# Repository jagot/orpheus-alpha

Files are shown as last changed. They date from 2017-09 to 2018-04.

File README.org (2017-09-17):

#+TITLE: Ορφέας Άλφα preamplifier
#+AUTHOR: Stefanos Carlström
#+EMAIL: stefanos.carlstrom@gmail.com

A simple preamplifier based around OPA2134 as buffer stage and PGA2311
as volume controller. A PSU (design [[https://www.muffsy.com/build-the-muffsy-psu-v3.html][courtesy of Muffsy]]) is also
present on the board, which is to be powered with 6VAC. Input signal
should be around Red Book standard.

[[./orpheus-alpha.pdf][Schematic]]

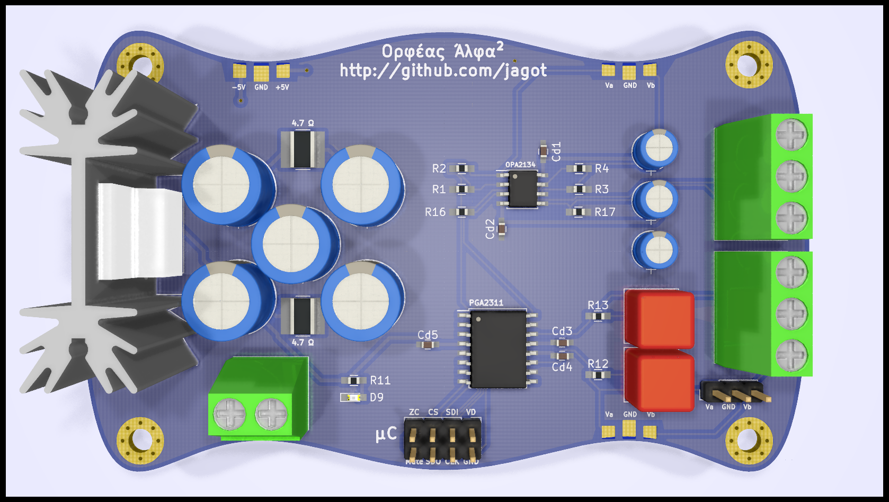
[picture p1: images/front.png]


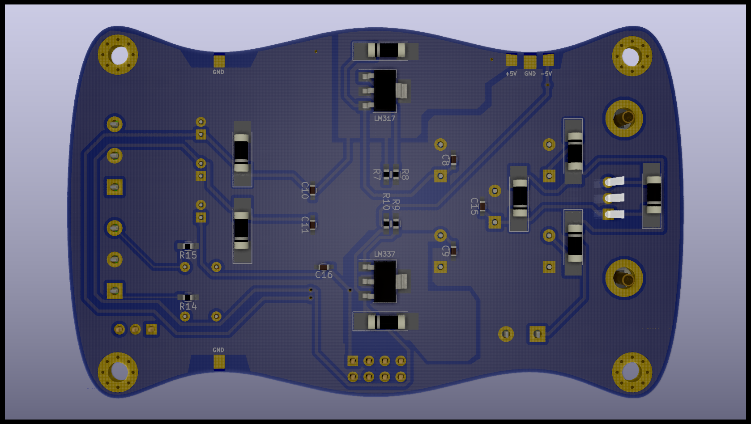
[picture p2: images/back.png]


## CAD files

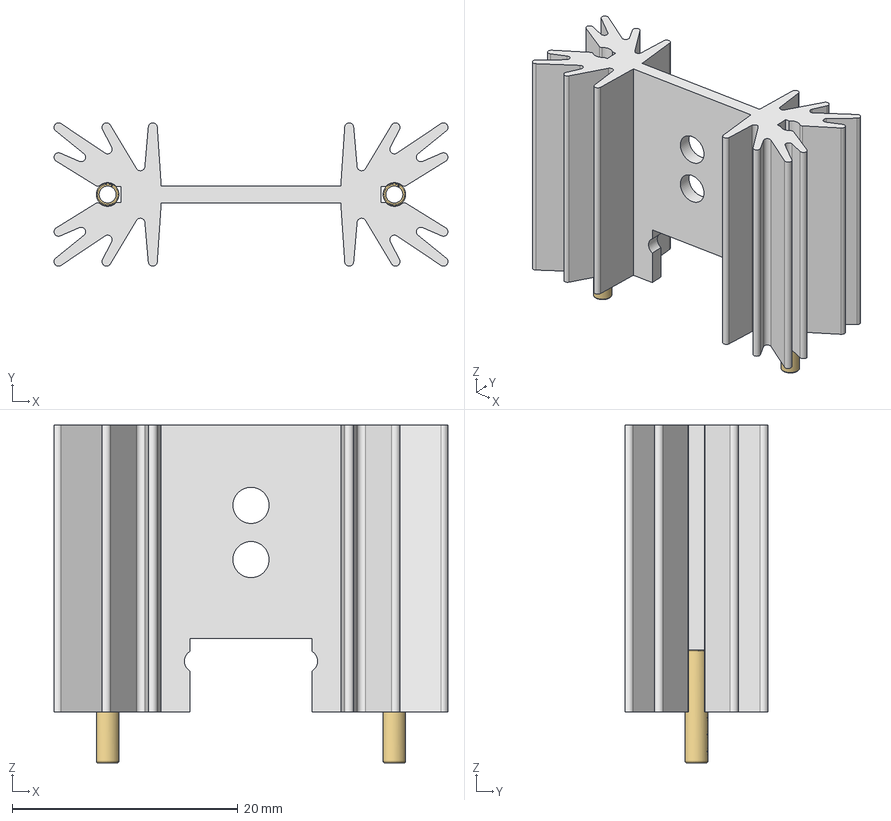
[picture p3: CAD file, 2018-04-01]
shapes3D/sk_104_25.4_sts.stp
34.9 x 12.7 x 29.9 mm
A9001B20100008S x 2

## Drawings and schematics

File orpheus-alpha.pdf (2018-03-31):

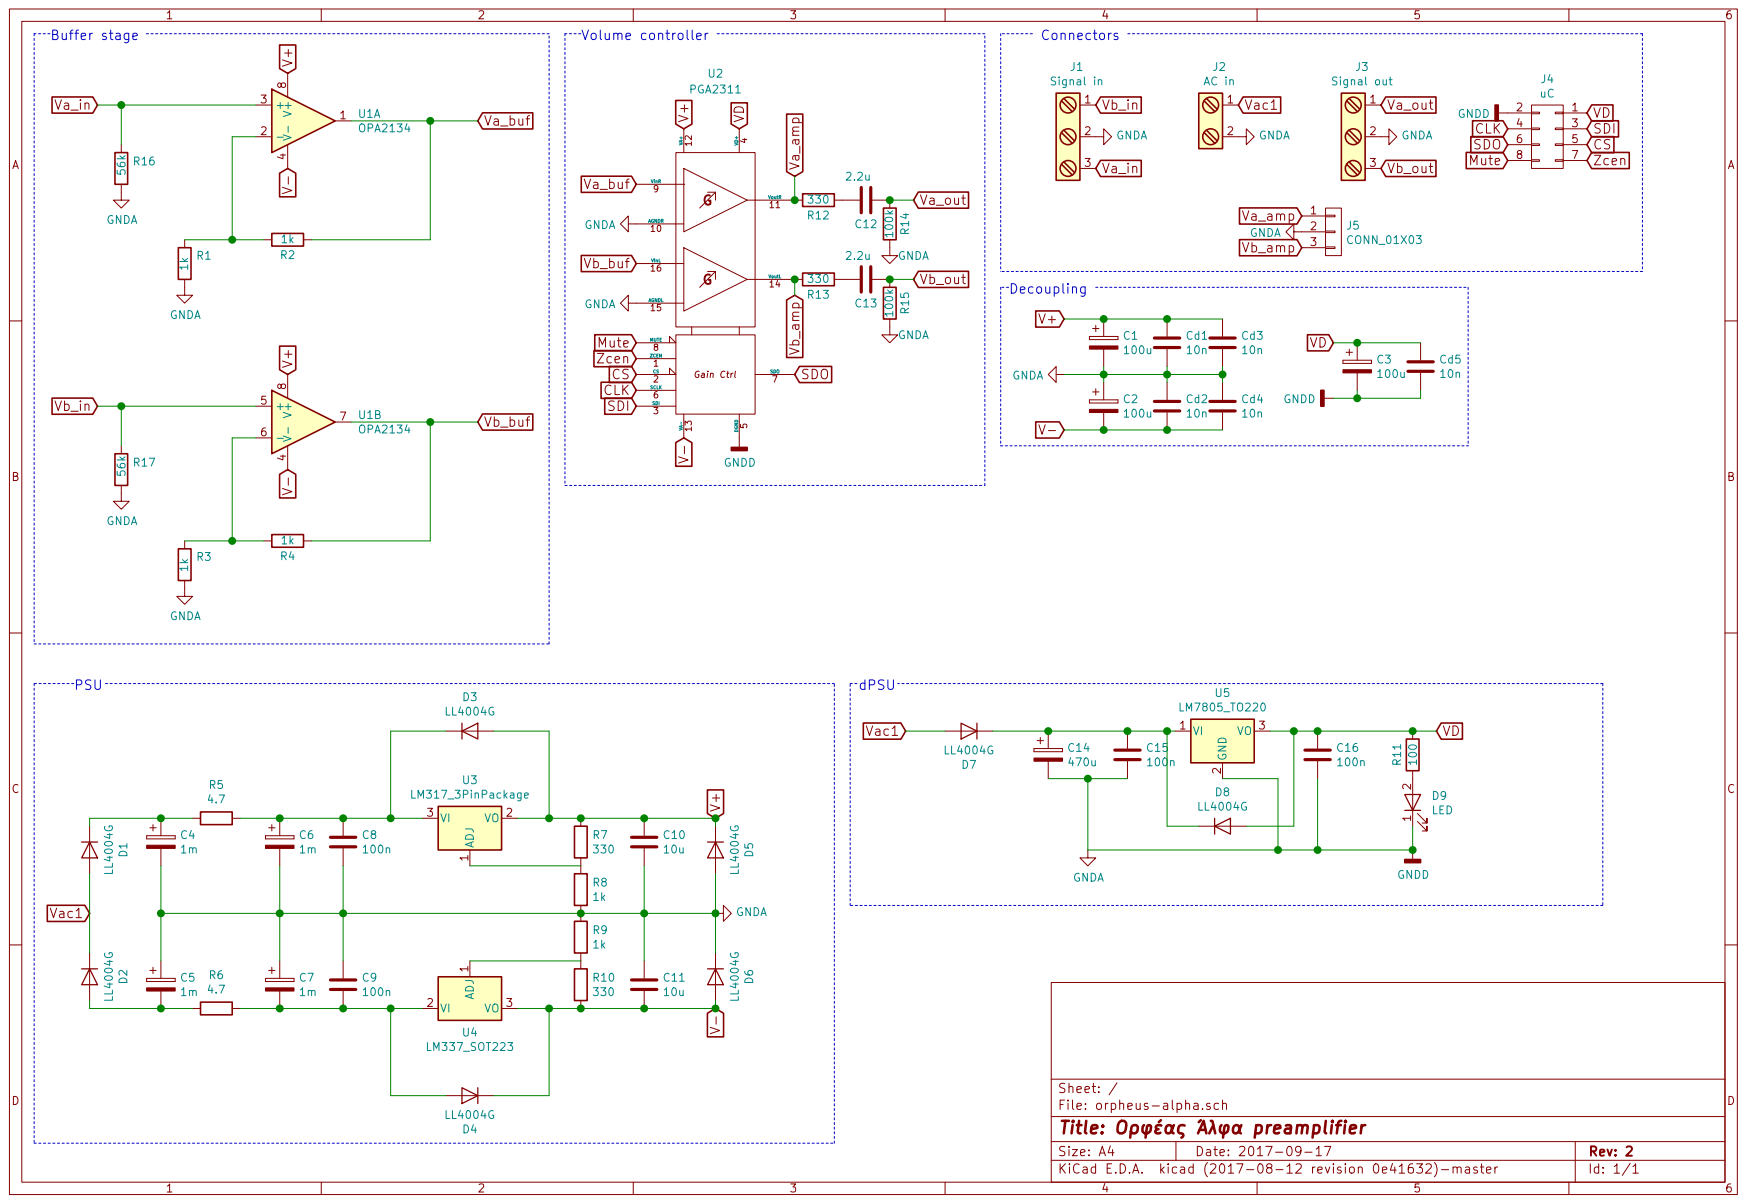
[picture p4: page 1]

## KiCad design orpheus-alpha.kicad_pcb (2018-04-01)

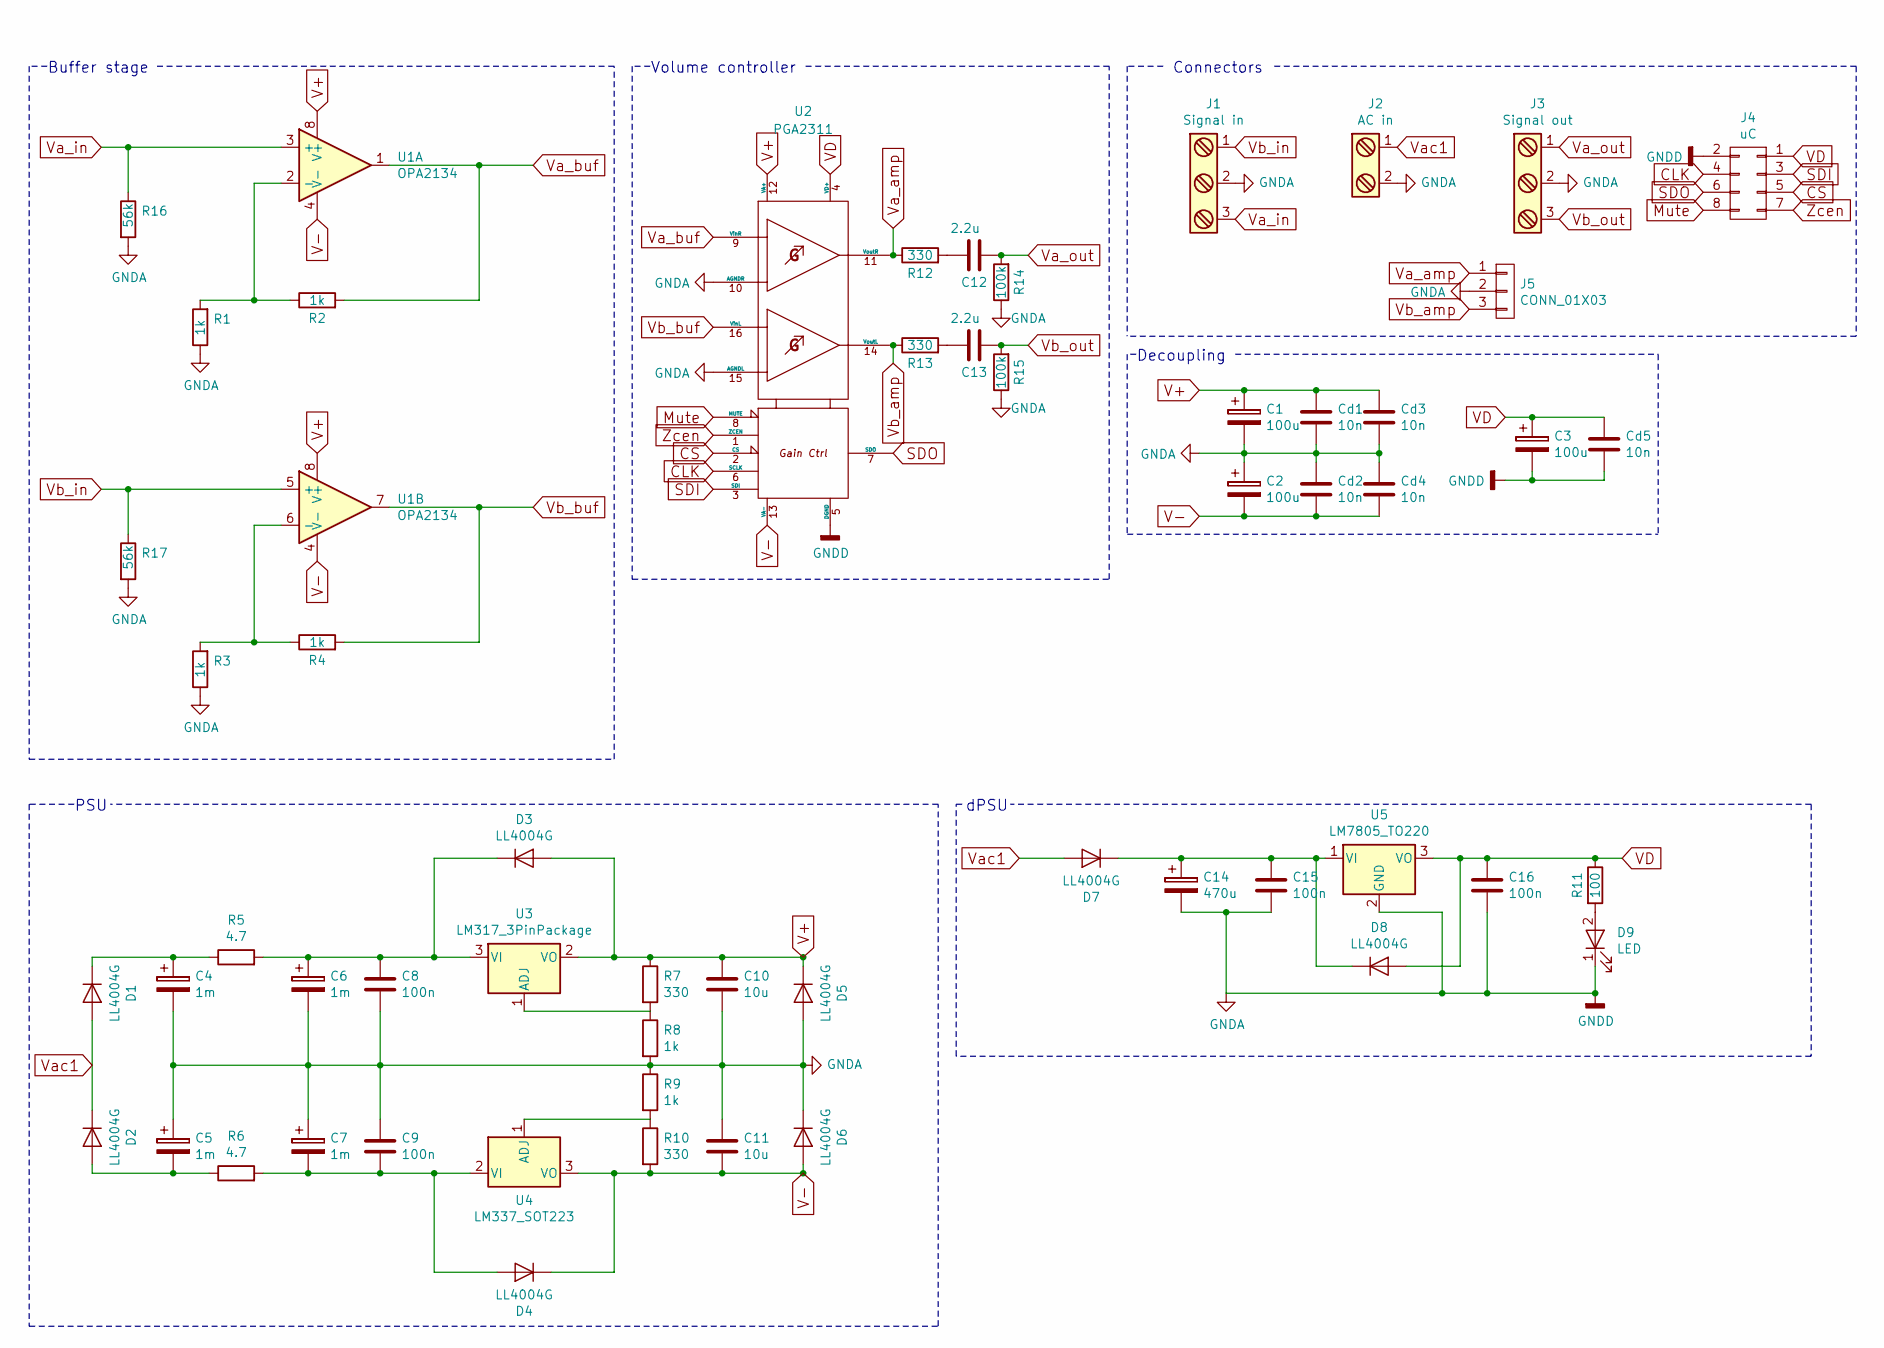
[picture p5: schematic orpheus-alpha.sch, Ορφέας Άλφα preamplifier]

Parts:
C1, C2, C3: 100u; CP_Radial_D5.0mm_P2.00mm; Voltage 16V
C4, C5, C6, C7: 1m; CP_Radial_D10.0mm_P5.00mm; Voltage 25V
C8, C9, C15, C16: 100n; C_0603_HandSoldering
C10, C11: 10u; C_0603_HandSoldering
C12, C13: 2.2u; C_Rect_L7.2mm_W7.2mm_P5.00mm_FKS2_FKP2_MKS2_MKP2
C14: 470u; CP_Radial_D10.0mm_P5.00mm; Voltage 25V
Cd1, Cd2, Cd3, Cd4, Cd5: 10n; C_0603_HandSoldering
D1, D2, D3, D4, D5, D6, D7, D8: LL4004G; D_MELF_Handsoldering
D9: LED; LED_0603_HandSoldering
J1: Signal in; TerminalBlock_Pheonix_MKDS1.5-3pol
J2: AC in; TerminalBlock_Pheonix_MKDS1.5-2pol
J3: Signal out; TerminalBlock_Pheonix_MKDS1.5-3pol
J4: uC; Pin_Header_Straight_2x04_Pitch2.54mm
J5: CONN_01X03; Pin_Header_Straight_1x03_Pitch2.54mm
R1, R2, R3, R4, R8, R9: 1k; R_0603_HandSoldering; Tolerance 1%
R5, R6: 4.7; R_1218_HandSoldering; Tolerance 1%
R7, R10, R12, R13: 330; R_0603_HandSoldering; Tolerance 1%
R11: 100; R_0603_HandSoldering; Tolerance 1%
R14, R15: 100k; R_0603_HandSoldering; Tolerance 1%
R16, R17: 56k; R_0603_HandSoldering; Tolerance 1%
U1: OPA2134; SOIC-8_3.9x4.9mm_Pitch1.27mm
U2: PGA2311; SOIC-16W_7.5x10.3mm_Pitch1.27mm
U3: LM317_3PinPackage; SOT-223-3Lead_TabPin2
U4: LM337_SOT223; SOT-223-3Lead_TabPin2
U5: LM7805_TO220; TO-220_Vertical

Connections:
CLK: J4.4, U2.6 (SCLK)
CS: J4.5, U2.2 (CS)
GNDA: C1.2, C2.1, C3.2, C4.2, C5.1, C6.2, C7.1, C8.2, C9.1, C10.2, C11.1, C14.2, C15.2, C16.2, Cd1.2, Cd2.1, Cd3.2, Cd4.1, Cd5.2, D5.2 (A), D6.1 (K), D9.1 (K), J1.2, J2.2, J3.2, J4.2, J5.2, R1.1, R3.1, R8.2, R9.1, R14.1, R15.1, R16.2, R17.2, U2.5 (DGND), U2.10 (AGNDR), U2.15 (AGNDL), U5.2 (GND)
Mute: J4.8, U2.8 (MUTE)
unnamed: C4.1, D1.1 (K), R5.1
unnamed: C5.2, D2.2 (A), R6.1
unnamed: C6.1, C8.1, D3.1 (K), R5.2, U3.3 (VI)
unnamed: C7.2, C9.2, D4.2 (A), R6.2, U4.2 (VI)
unnamed: C12.2, R12.2
unnamed: C13.2, R13.2
unnamed: C14.1, C15.1, D7.1 (K), D8.1 (K), U5.1 (VI)
unnamed: D9.2 (A), R11.2
unnamed: R1.2, R2.1, U1.2 (-)
unnamed: R3.2, R4.1, U1.6 (-)
unnamed: R7.2, R8.1, U3.1 (ADJ)
unnamed: R9.2, R10.1, U4.1 (ADJ)
SDI: J4.3, U2.3 (SDI)
SDO: J4.6, U2.7 (SDO)
V+: C1.1, C10.1, Cd1.1, Cd3.1, D3.2 (A), D5.1 (K), R7.1, U1.8 (V+), U2.12 (VA+), U3.2 (VO)
V-: C2.2, C11.2, Cd2.2, Cd4.2, D4.1 (K), D6.2 (A), R10.2, U1.4 (V-), U2.13 (VA-), U4.3 (VO)
VD: C3.1, C16.1, Cd5.1, D8.2 (A), J4.1, R11.1, U2.4 (VD+), U5.3 (VO)
Va_amp: J5.1, R12.1, U2.11 (VoutR)
Va_buf: R2.2, U1.1, U2.9 (VinR)
Va_in: J1.3, R16.1, U1.3 (+)
Va_out: C12.1, J3.1, R14.2
Vac1: D1.2 (A), D2.1 (K), D7.2 (A), J2.1
Vb_amp: J5.3, R13.1, U2.14 (VoutL)
Vb_buf: R4.2, U1.7, U2.16 (VinL)
Vb_in: J1.1, R17.1, U1.5 (+)
Vb_out: C13.1, J3.3, R15.2
Zcen: J4.7, U2.1 (ZCEN)

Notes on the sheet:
Decoupling
Buffer stage
Volume controller
Connectors
PSU
dPSU

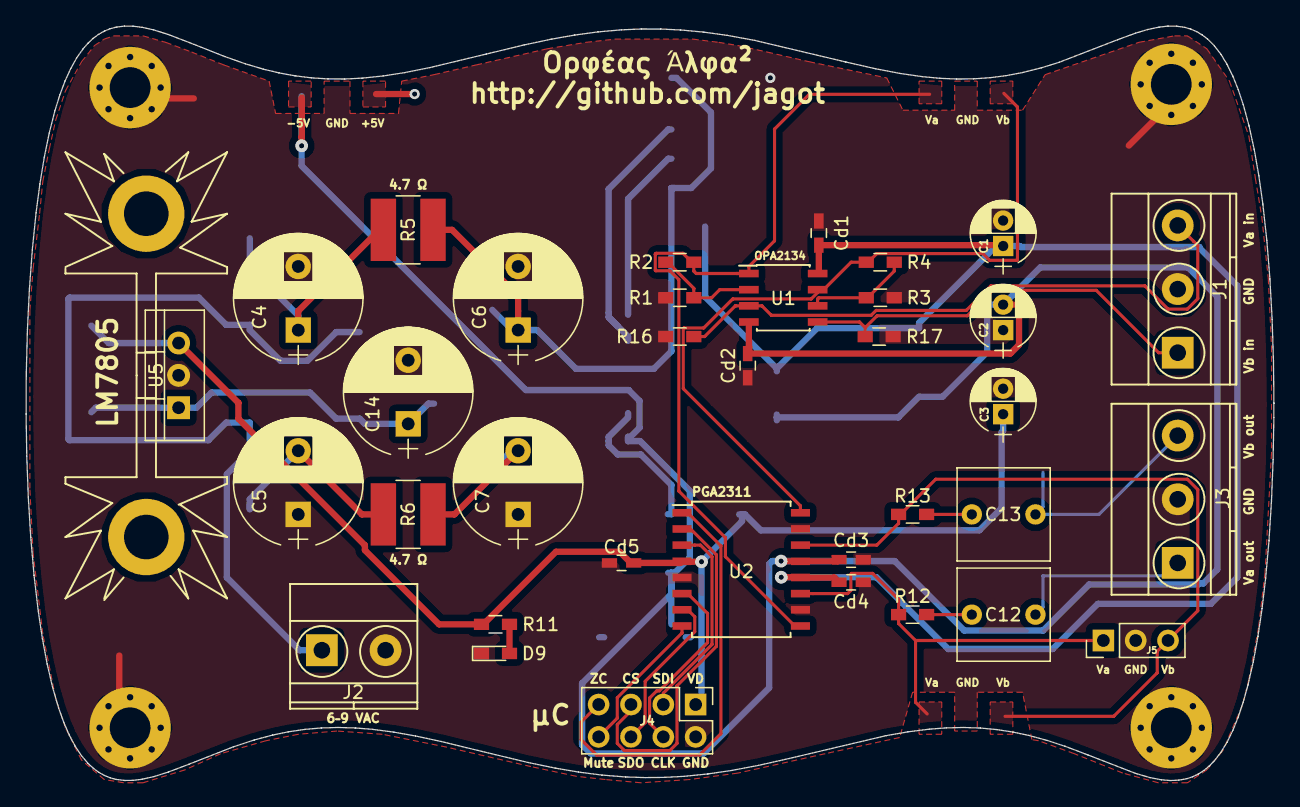
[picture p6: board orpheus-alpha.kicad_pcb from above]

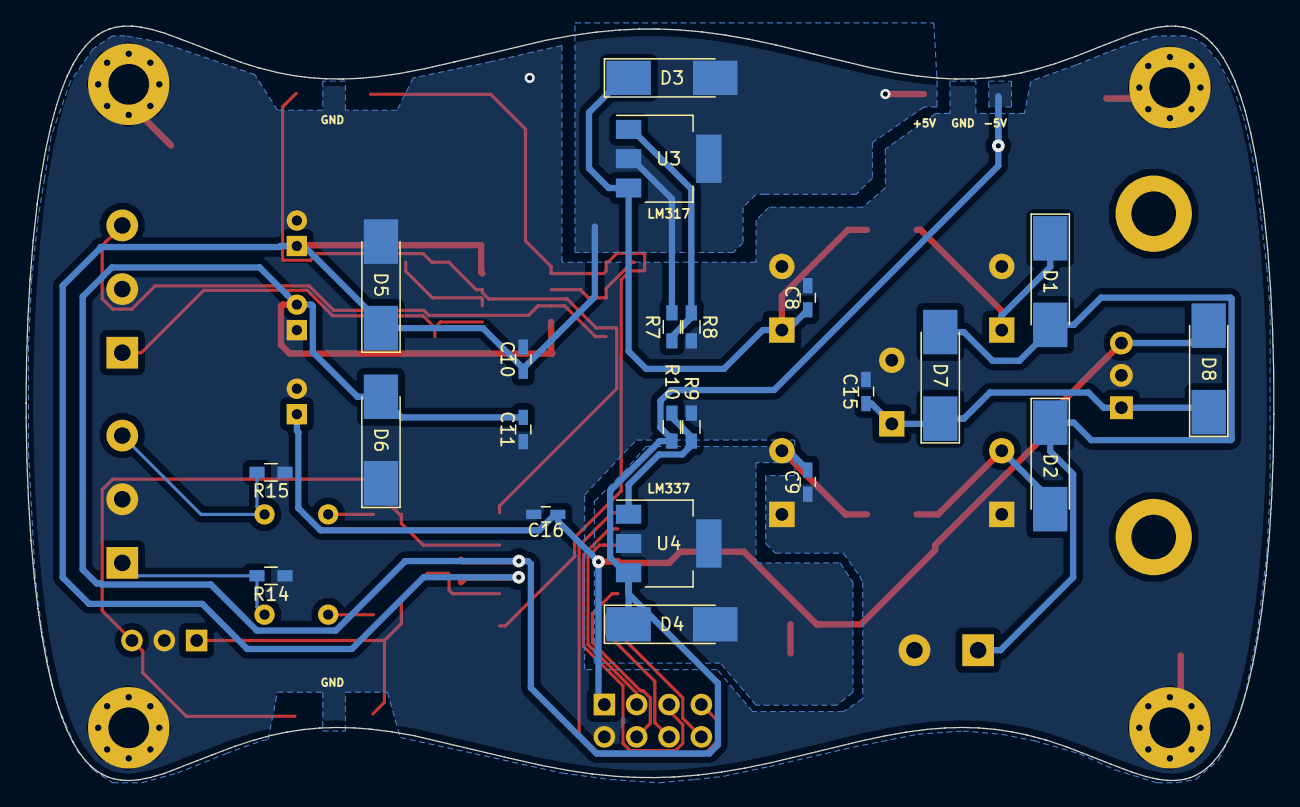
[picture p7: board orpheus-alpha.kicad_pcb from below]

Board: 2 copper layers, 98.0 x 59.3 mm, 57 parts (22 on the bottom side), 31 nets.

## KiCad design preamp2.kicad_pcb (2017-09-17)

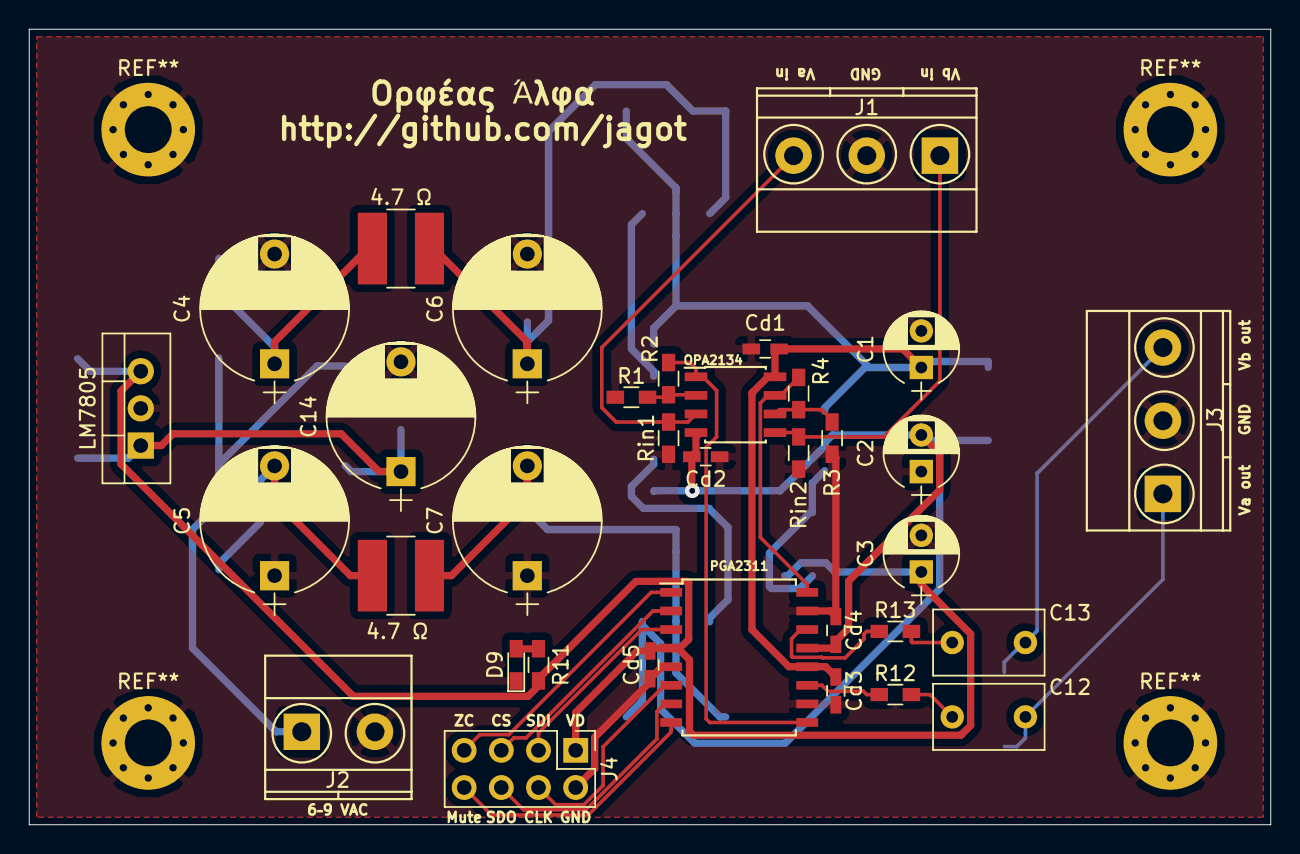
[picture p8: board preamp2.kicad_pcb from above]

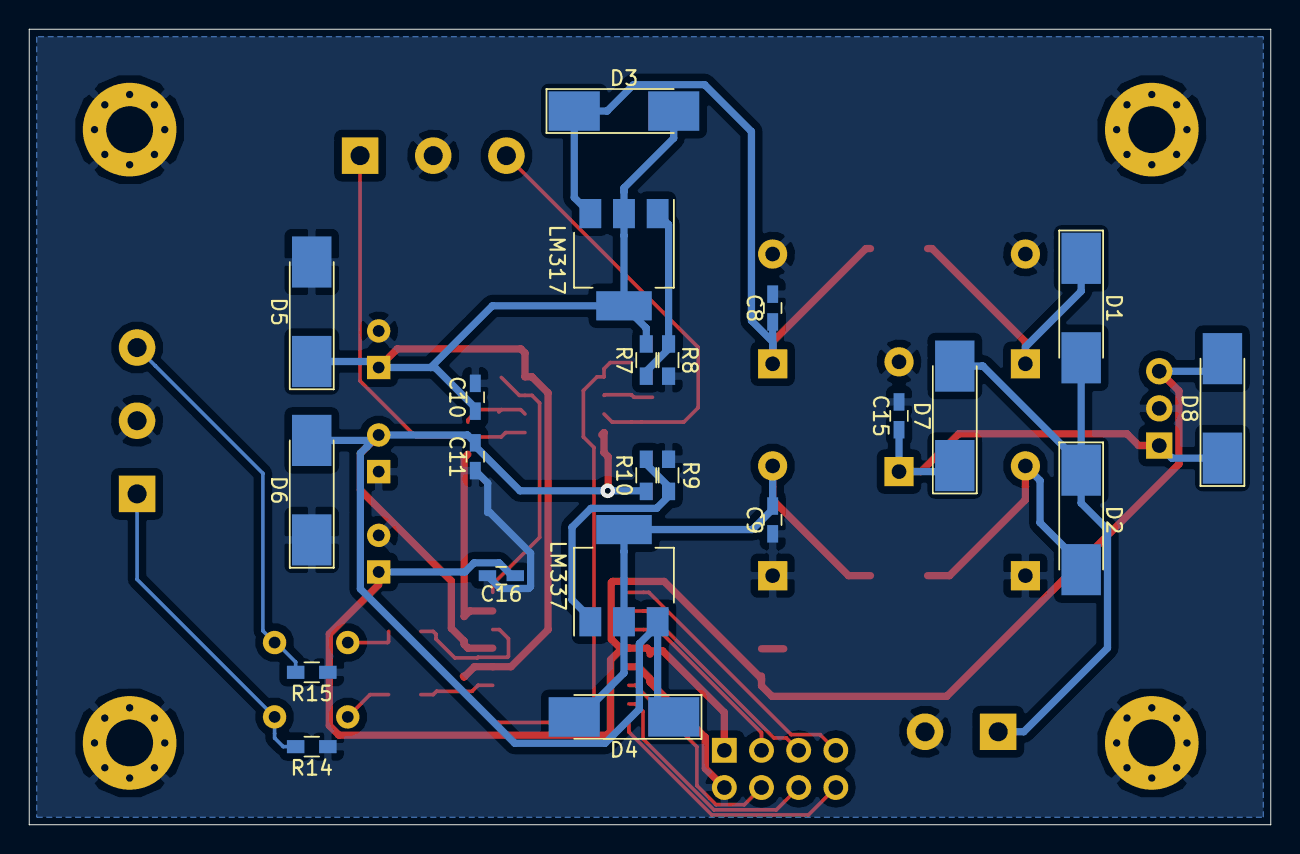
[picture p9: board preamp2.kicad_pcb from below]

Board: 2 copper layers, 84.8 x 54.4 mm, 56 parts (22 on the bottom side), 31 nets.

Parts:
4.7 Ω, 4.7 Ω#2: 4.7; R_1218_HandSoldering
C1, C2, C3: 100u; CP_Radial_D5.0mm_P2.50mm
C4, C5, C6, C7: 1m; CP_Radial_D10.0mm_P7.50mm
C8, C9, C15, C16: 100n; C_0603_HandSoldering
C10, C11: 10u; C_0603_HandSoldering
C12, C13: 2.2u; C_Disc_D7.5mm_W4.4mm_P5.00mm
C14: 470u; CP_Radial_D10.0mm_P7.50mm
Cd1, Cd2, Cd3, Cd4, Cd5: 10n; C_0603_HandSoldering
D1, D2, D3, D4, D5, D6, D7, D8: LL4004G; D_MELF_Handsoldering
D9: LED; LED_0603_HandSoldering
J1: Signal in; TerminalBlock_Pheonix_MKDS1.5-3pol
J2: AC in; TerminalBlock_Pheonix_MKDS1.5-2pol
J3: Signal out; TerminalBlock_Pheonix_MKDS1.5-3pol
J4: uC; Pin_Header_Straight_2x04_Pitch2.54mm
LM317: LM317_3PinPackage; SOT-223-3Lead_TabPin2
LM337: LM337_SOT223; SOT-223-3Lead_TabPin2
LM7805: LM7805_TO220; TO-220_Vertical
OPA2134: OPA2134; SOIC-8_3.9x4.9mm_Pitch1.27mm
PGA2311: PGA2311; SOIC-16W_7.5x10.3mm_Pitch1.27mm
R1, R2, R3, R4: 1k; R_0603_HandSoldering
R7, R10: 910; R_0603_HandSoldering
R8, R9: 2k7; R_0603_HandSoldering
R11: 100; R_0603_HandSoldering
R12, R13: 300; R_0603_HandSoldering
R14, R15: 100k; R_0603_HandSoldering
Rin1, Rin2: 56k; R_0603_HandSoldering

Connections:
CLK: J4.4, PGA2311.6
CS: J4.5, PGA2311.2
GNDA: C1.2, C2.1, C3.2, C4.2, C5.1, C6.2, C7.1, C8.2, C9.1, C10.2, C11.1, C14.2, C15.2, C16.2, Cd1.2, Cd2.1, Cd3.2, Cd4.1, Cd5.2, D5.2, D6.1, D9.1, J1.2, J2.2, J3.2, J4.2, LM7805.2, PGA2311.5, PGA2311.10, PGA2311.15, R1.1, R3.1, R8.2, R9.1, R14.1, R15.1, Rin1.2, Rin2.2
Mute: J4.8, PGA2311.8
unnamed: 4.7 Ω.1, C4.1, D1.1
unnamed: 4.7 Ω#2.1, C5.2, D2.2
unnamed: 4.7 Ω.2, C6.1, C8.1, D3.1, LM317.3
unnamed: 4.7 Ω#2.2, C7.2, C9.2, D4.2, LM337.2
unnamed: C12.2, R12.2
unnamed: C13.2, R13.2
unnamed: C14.1, C15.1, D7.1, D8.1, LM7805.1
unnamed: D9.2, R11.2
unnamed: OPA2134.2, R1.2, R2.1
unnamed: OPA2134.6, R3.2, R4.1
unnamed: LM317.1, R7.2, R8.1
unnamed: LM337.1, R9.2, R10.1
unnamed: PGA2311.11, R12.1
unnamed: PGA2311.14, R13.1
SDI: J4.3, PGA2311.3
SDO: J4.6, PGA2311.7
V+: C1.1, C10.1, Cd1.1, Cd3.1, D3.2, D5.1, LM317.2, OPA2134.8, PGA2311.12, R7.1
V-: C2.2, C11.2, Cd2.2, Cd4.2, D4.1, D6.2, LM337.3, OPA2134.4, PGA2311.13, R10.2
VD: C3.1, C16.1, Cd5.1, D8.2, J4.1, LM7805.3, PGA2311.4, R11.1
Va_buf: OPA2134.1, PGA2311.9, R2.2
Va_in: J1.3, OPA2134.3, Rin1.1
Va_out: C12.1, J3.1, R14.2
Vac1: D1.2, D2.1, D7.2, J2.1
Vb_buf: OPA2134.7, PGA2311.16, R4.2
Vb_in: J1.1, OPA2134.5, Rin2.1
Vb_out: C13.1, J3.3, R15.2
Zcen: J4.7, PGA2311.1

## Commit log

2017-09-16 Decreased resistor value to increase possible current
    [preamp2.sch]
2017-09-17 Increased pin header size
    [preamp2.kicad_pcb, preamp2.sch]
2017-09-17 Added some silk screen annotations
    [preamp2.kicad_pcb]
2017-09-17 Renamed project
    [orpheus-alpha.kicad_pcb, orpheus-alpha.sch]
2017-09-17 Updated schematic
2017-09-18 Small changes, changed output coupling caps to film type
    [orpheus-alpha.kicad_pcb, orpheus-alpha.sch]
2017-09-18 Added part numbers
    [orpheus-alpha.kicad_pcb, orpheus-alpha.sch]
2017-09-27 Changed some part values and part numbers
    [orpheus-alpha.kicad_pcb, orpheus-alpha.sch]
2017-10-15 Added optional power connectors
    [orpheus-alpha.kicad_pcb, orpheus-alpha.sch]
2018-03-31 New layout, "debug" connection pads at the edge
    [orpheus-alpha.kicad_pcb, orpheus-alpha.sch]
2018-04-01 Added heatsinks
    [orpheus-alpha.kicad_pcb, orpheus-alpha.sch, sk_104_25.4_sts.stp]
2018-04-01 Changed footprint of PSU capacitors
    [orpheus-alpha.kicad_pcb, orpheus-alpha.sch]
